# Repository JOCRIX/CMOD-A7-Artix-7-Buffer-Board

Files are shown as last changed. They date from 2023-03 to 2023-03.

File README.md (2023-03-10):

# **Buffer Board for the CMOD A7 Artix 7 family of FPGA development boards**


## **Purpose of the project**
The development boards for these FPGA's are costly and, sadly, a little fumbling around
could easily claim it's life, so, the purpose of this project is to create a board that can buffer the I/O pins
on the Digilent CMOD A7 FPGA board. (Mfr: 410-328-35, Mouser.com nr:424-410-328-35).

All design files are for KiCad. Feel free to export the GERBERS and do w/e with it.

## **How it works**
The board uses TXB0108 bidirectional and auto-direction sensing buffers to buffer all the I/O pins. The buffers
do not require any signal to set them as inputs or outputs, this is handled automatically on the fly. Each pin
has a maximum I/O current of 50mA and a package total of 100mA per buffer IC. The purpose of the board is 
that the drivers will fail before the FPGA does, that is OK. The FPGA is connected to the buffers through
330 ohm resistors, so, if the buffers fail in a spectacular way the FPGA output current is limited to stay
within specification of the Artix 7 35T FPGA.

The rise and fall times of the output of the buffer board has been tested and both rise and fall times are 4 < t < 5 [nS].

The two ADC input pins AIN/NP15, AIN/NP16 are protected against overvoltage conditions with diodes.

## **Requirements / BOM**

1x CMOD A7 FPGA Board - https://www.mouser.dk/ProductDetail/Digilent/410-328-35?qs=iHX4uCgIbgPRh1v3D3f51A%3D%3D
<br>
6x TXB0108 [TSSOP20]
<br>
11x YC324, or similar, 330 ohm resistor array.
<br>
2x 24 Pin Female headers with 2.54mm pitch
<br>
2x 24 Pin Female/Male header with 2.54mm pitch
<br>
1x LD117S533TR [SOT223]
<br>
7x 100nF >6.3V [0805]
<br>
1x 0603 LED (Doesn't really matter but it looks cool!)
<br>
1x 560R [0805]
<br>
1x 10uF [0805]
<br>
4x BAT54 [SOD-123]

## Hope you like Warhammer..



### Notes for users
V1 of this board has a fault so **PIO26 [FPGA PIN: R3] is not connected**. This is to be fixed in a future revision.
The problem can be fixed with a jumper wire for now. (Or just edit the .sch but w/e :)).

The green trace shows the connection that should be made for R3 to work. Easily fixed in either case..


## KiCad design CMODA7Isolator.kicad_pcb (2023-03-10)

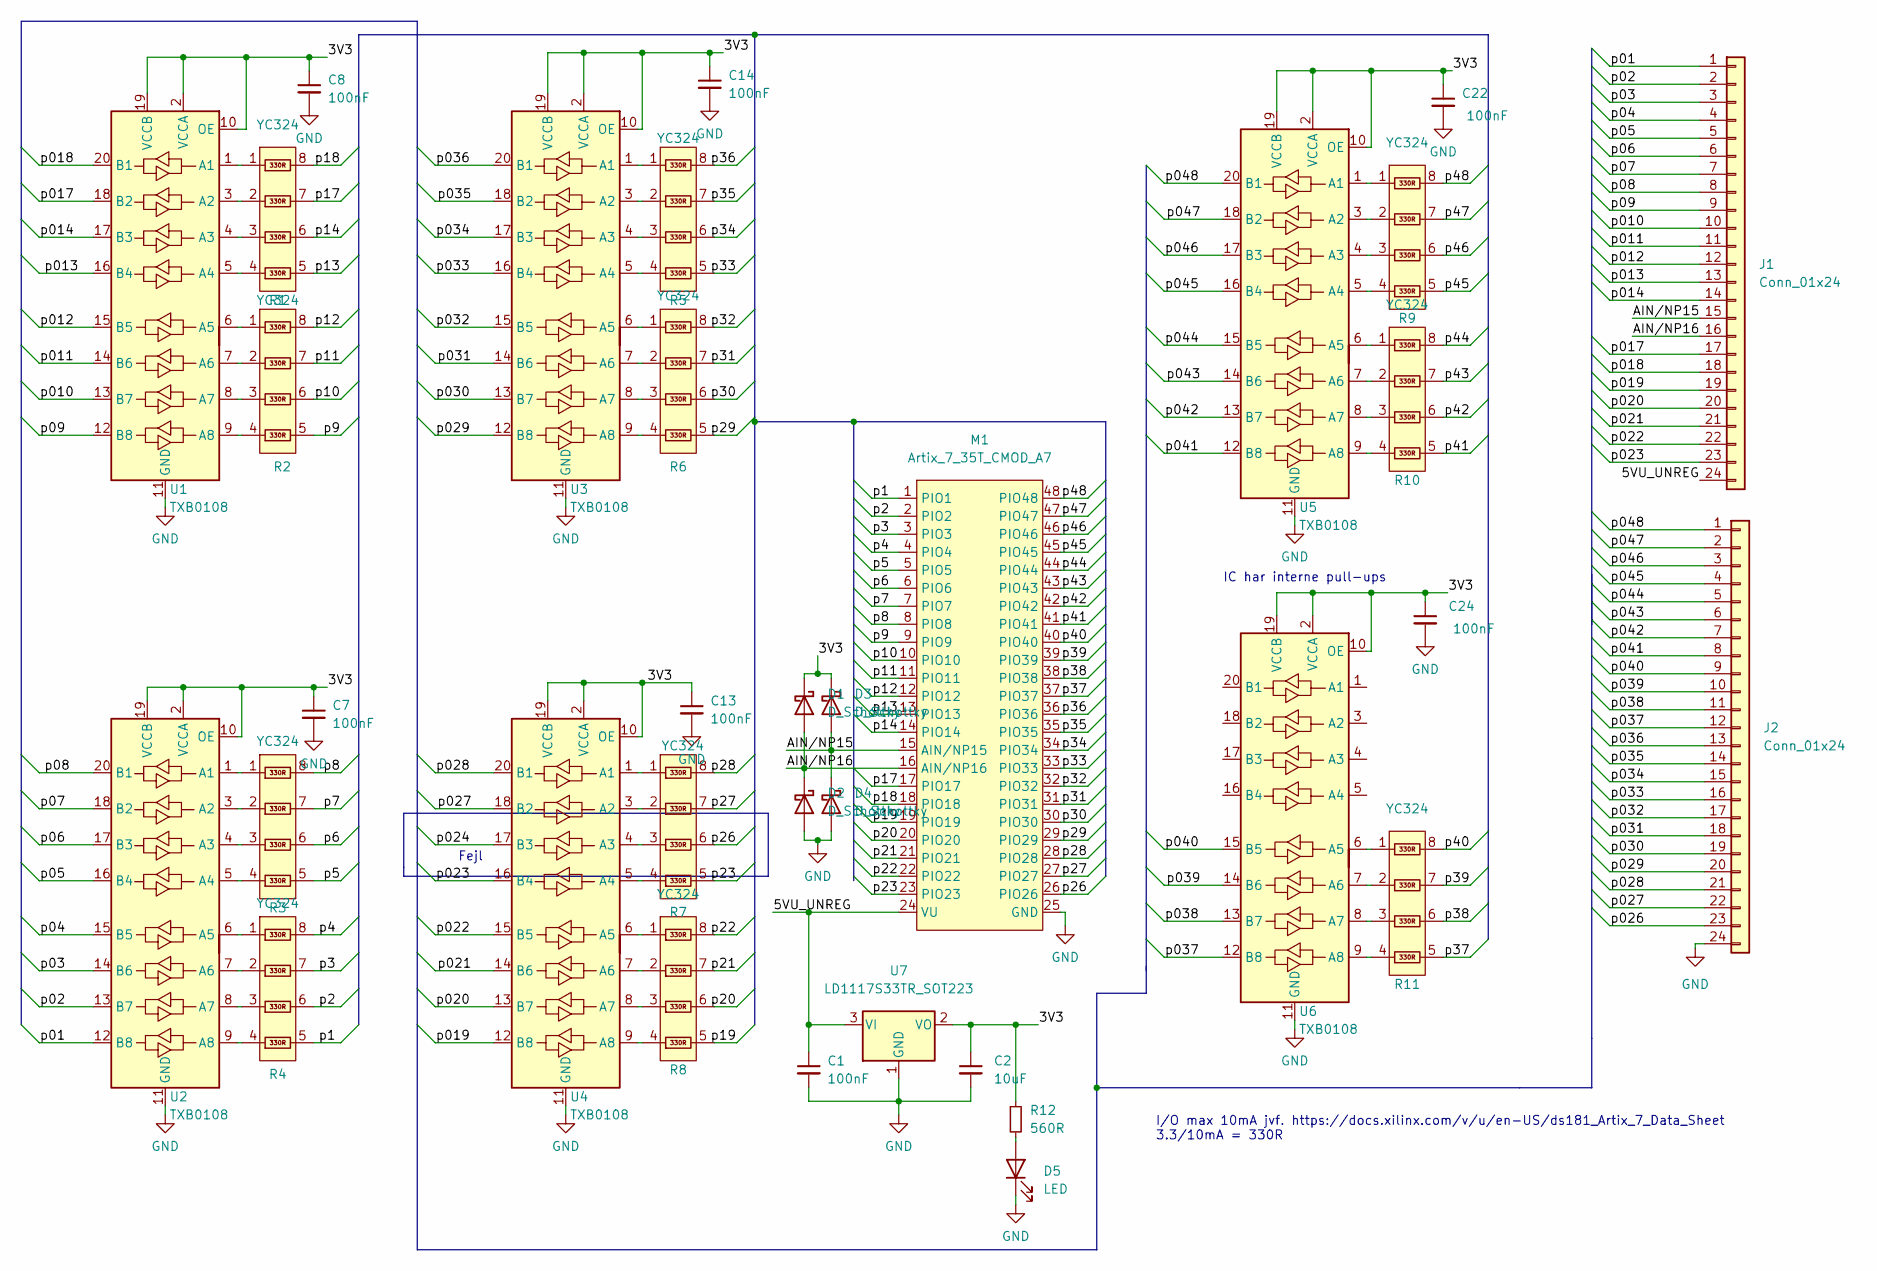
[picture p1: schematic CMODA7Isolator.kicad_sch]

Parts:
C1, C7, C8, C13, C14, C22, C24: 100nF; C_0805_2012Metric_Pad1.18x1.45mm_HandSolder
C2: 10uF; C_0805_2012Metric_Pad1.18x1.45mm_HandSolder
D1, D2, D3, D4: D_Schottky; D_SOD-123
D5: LED; LED_0603_1608Metric
J1, J2: Conn_01x24; PinHeader_1x24_P2.54mm_Vertical
M1: Artix_7_35T_CMOD_A7; CMOD A7 Module
R1, R2, R3, R4, R5, R6, R7, R8, R9, R10, R11: YC324; YC-TC 124 8Pin-4R
R12: 560R; R_0805_2012Metric_Pad1.20x1.40mm_HandSolder
U1, U2, U3, U4, U5, U6: TXB0108; TSSOP-20_4.4x6.5mm_P0.65mm
U7: LD1117S33TR_SOT223; SOT-223-3_TabPin2

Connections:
/3V3: C2.1, C7.1, C8.1, C13.1, C14.1, C22.1, C24.1, D1.1 (K), D3.1 (K), R12.1, U1.2 (VCCA), U1.10 (OE), U1.19 (VCCB), U2.2 (VCCA), U2.10 (OE), U2.19 (VCCB), U3.2 (VCCA), U3.10 (OE), U3.19 (VCCB), U4.2 (VCCA), U4.10 (OE), U4.19 (VCCB), U5.2 (VCCA), U5.10 (OE), U5.19 (VCCB), U6.2 (VCCA), U6.10 (OE), U6.19 (VCCB), U7.2 (VO)
/5VU_UNREG: C1.1, J1.24, M1.24 (VU), U7.3 (VI)
/AIN/NP15: D3.2 (A), D4.1 (K), J1.15, M1.15 (AIN/NP15)
/AIN/NP16: D1.2 (A), D2.1 (K), J1.16, M1.16 (AIN/NP16)
/p01: J1.1, U2.12 (B8)
/p1: M1.1 (PIO1), R4.5
/p02: J1.2, U2.13 (B7)
/p2: M1.2 (PIO2), R4.6
/p03: J1.3, U2.14 (B6)
/p3: M1.3 (PIO3), R4.7
/p04: J1.4, U2.15 (B5)
/p4: M1.4 (PIO4), R4.8
/p5: M1.5 (PIO5), R3.5
/p05: J1.5, U2.16 (B4)
/p6: M1.6 (PIO6), R3.6
/p06: J1.6, U2.17 (B3)
/p7: M1.7 (PIO7), R3.7
/p07: J1.7, U2.18 (B2)
/p8: M1.8 (PIO8), R3.8
/p08: J1.8, U2.20 (B1)
/p09: J1.9, U1.12 (B8)
/p9: M1.9 (PIO9), R2.5
/p010: J1.10, U1.13 (B7)
/p10: M1.10 (PIO10), R2.6
/p011: J1.11, U1.14 (B6)
/p11: M1.11 (PIO11), R2.7
/p012: J1.12, U1.15 (B5)
/p12: M1.12 (PIO12), R2.8
/p013: J1.13, U1.16 (B4)
/p13: M1.13 (PIO13), R1.5
/p014: J1.14, U1.17 (B3)
/p14: M1.14 (PIO14), R1.6
/p017: J1.17, U1.18 (B2)
/p17: M1.17 (PIO17), R1.7
/p018: J1.18, U1.20 (B1)
/p18: M1.18 (PIO18), R1.8
/p19: M1.19 (PIO19), R8.5
/p019: J1.19, U4.12 (B8)
/p20: M1.20 (PIO20), R8.6
/p020: J1.20, U4.13 (B7)
/p21: M1.21 (PIO21), R8.7
/p021: J1.21, U4.14 (B6)
/p22: M1.22 (PIO22), R8.8
/p022: J1.22, U4.15 (B5)
/p23: M1.23 (PIO23), R7.5
/p023: J1.23, U4.16 (B4)
/p024: U4.17 (B3)
/p26: M1.26 (PIO26), R7.6
/p026: J2.23
/p27: M1.27 (PIO27), R7.7
/p027: J2.22, U4.18 (B2)
/p28: M1.28 (PIO28), R7.8
/p028: J2.21, U4.20 (B1)
/p29: M1.29 (PIO29), R6.5
/p029: J2.20, U3.12 (B8)
/p30: M1.30 (PIO30), R6.6
/p030: J2.19, U3.13 (B7)
/p31: M1.31 (PIO31), R6.7
/p031: J2.18, U3.14 (B6)
/p32: M1.32 (PIO32), R6.8
/p032: J2.17, U3.15 (B5)
/p33: M1.33 (PIO33), R5.5
/p033: J2.16, U3.16 (B4)
/p34: M1.34 (PIO34), R5.6
/p034: J2.15, U3.17 (B3)
/p35: M1.35 (PIO35), R5.7
/p035: J2.14, U3.18 (B2)
/p36: M1.36 (PIO36), R5.8
/p036: J2.13, U3.20 (B1)
/p37: M1.37 (PIO37), R11.5
/p037: J2.12, U6.12 (B8)
/p38: M1.38 (PIO38), R11.6
/p038: J2.11, U6.13 (B7)
/p39: M1.39 (PIO39), R11.7
/p039: J2.10, U6.14 (B6)
/p40: M1.40 (PIO40), R11.8
/p040: J2.9, U6.15 (B5)
/p41: M1.41 (PIO41), R10.5
/p041: J2.8, U5.12 (B8)
/p42: M1.42 (PIO42), R10.6
/p042: J2.7, U5.13 (B7)
/p43: M1.43 (PIO43), R10.7
/p043: J2.6, U5.14 (B6)
/p44: M1.44 (PIO44), R10.8
/p044: J2.5, U5.15 (B5)
/p45: M1.45 (PIO45), R9.5
/p045: J2.4, U5.16 (B4)
/p46: M1.46 (PIO46), R9.6
/p046: J2.3, U5.17 (B3)
/p47: M1.47 (PIO47), R9.7
/p047: J2.2, U5.18 (B2)
/p48: M1.48 (PIO48), R9.8
/p048: J2.1, U5.20 (B1)
GND: C1.2, C2.2, C7.2, C8.2, C13.2, C14.2, C22.2, C24.2, D2.2 (A), D4.2 (A), D5.1 (K), J2.24, M1.25 (GND), U1.11 (GND), U2.11 (GND), U3.11 (GND), U4.11 (GND), U5.11 (GND), U6.11 (GND), U7.1 (GND)
unnamed: R1.1, U1.1 (A1)
unnamed: R1.2, U1.3 (A2)
unnamed: R1.3, U1.4 (A3)
unnamed: R1.4, U1.5 (A4)
unnamed: R2.1, U1.6 (A5)
unnamed: R2.2, U1.7 (A6)
unnamed: R2.3, U1.8 (A7)
unnamed: R2.4, U1.9 (A8)
unnamed: R3.1, U2.1 (A1)
unnamed: R3.2, U2.3 (A2)
unnamed: R3.3, U2.4 (A3)
unnamed: R3.4, U2.5 (A4)
unnamed: R4.1, U2.6 (A5)
unnamed: R4.2, U2.7 (A6)
unnamed: R4.3, U2.8 (A7)
unnamed: R4.4, U2.9 (A8)
unnamed: R5.1, U3.1 (A1)
unnamed: R5.2, U3.3 (A2)
unnamed: R5.3, U3.4 (A3)
unnamed: R5.4, U3.5 (A4)
unnamed: R6.1, U3.6 (A5)
unnamed: R6.2, U3.7 (A6)
unnamed: R6.3, U3.8 (A7)
unnamed: R6.4, U3.9 (A8)
unnamed: R7.1, U4.1 (A1)
unnamed: R7.2, U4.3 (A2)
unnamed: R7.3, U4.4 (A3)
unnamed: R7.4, U4.5 (A4)
unnamed: R8.1, U4.6 (A5)
unnamed: R8.2, U4.7 (A6)
unnamed: R8.3, U4.8 (A7)
unnamed: R8.4, U4.9 (A8)
unnamed: R9.1, U5.1 (A1)
unnamed: R9.2, U5.3 (A2)
unnamed: R9.3, U5.4 (A3)
unnamed: R9.4, U5.5 (A4)
unnamed: R10.1, U5.6 (A5)
unnamed: R10.2, U5.7 (A6)
unnamed: R10.3, U5.8 (A7)
unnamed: R10.4, U5.9 (A8)
unnamed: R11.1, U6.6 (A5)
unnamed: R11.2, U6.7 (A6)
unnamed: R11.3, U6.8 (A7)
unnamed: R11.4, U6.9 (A8)
unnamed: D5.2 (A), R12.2

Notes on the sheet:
I/O max 10mA jvf. https://docs.xilinx.com/v/u/en-US/ds181_Artix_7_Data_Sheet 3.3/10mA = 330R
IC har interne pull-ups
Fejl

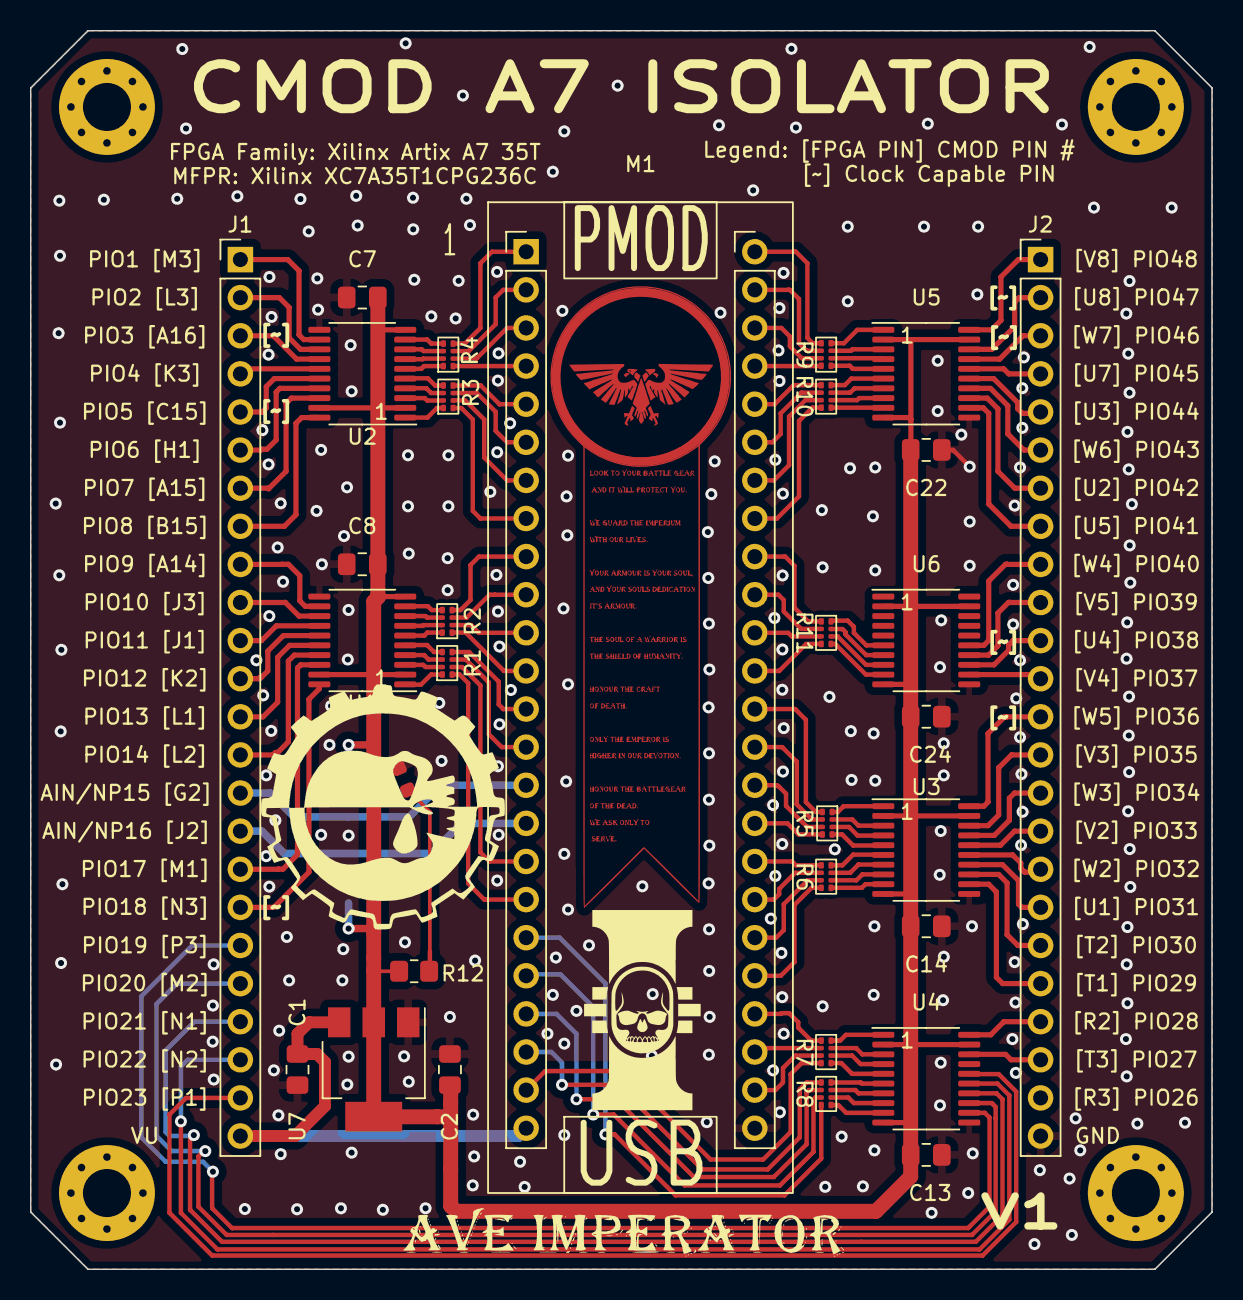
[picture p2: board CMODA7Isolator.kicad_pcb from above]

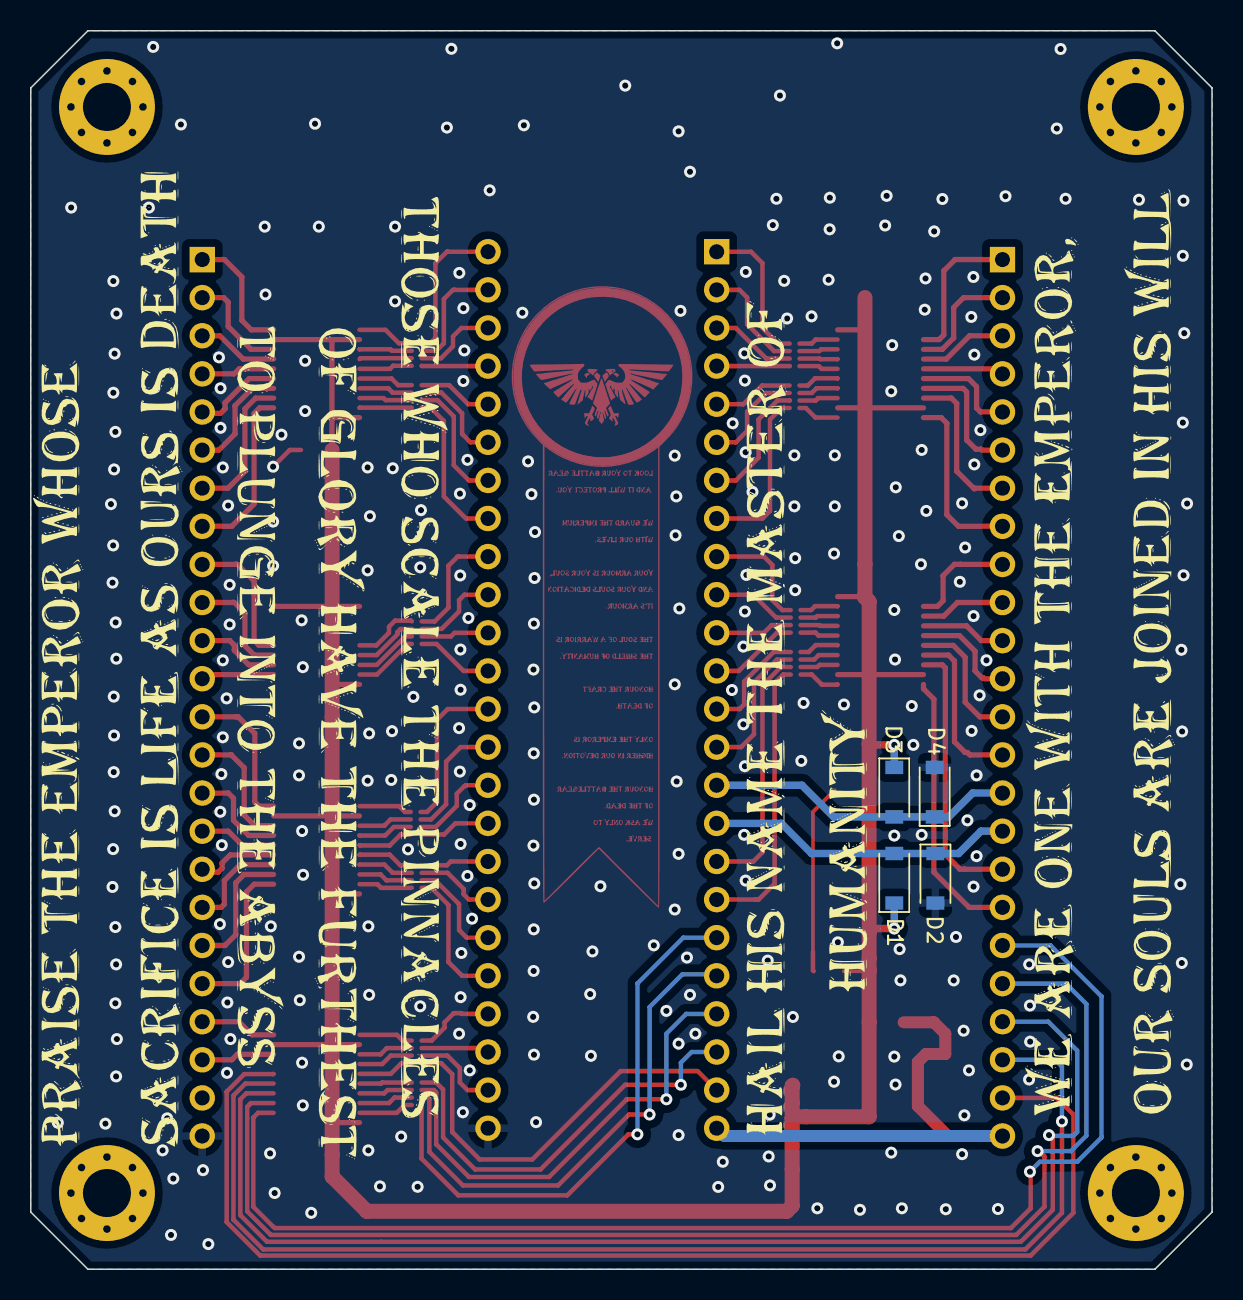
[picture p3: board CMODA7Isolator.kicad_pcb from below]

Board: 2 copper layers, 78.7 x 82.6 mm, 35 parts (4 on the bottom side), 137 nets.

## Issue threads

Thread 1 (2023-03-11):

Add Level Translating functionality

JOCRIX, 2023-03-11:
Sides A and B of the TXB0108's are currently both tied to 3.3V.

Make side B (output) switchable between 3.3V and 5V.

Make the switch happen with jumpers or DIP switches or something

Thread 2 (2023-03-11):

Change U4's position on the PCB

JOCRIX, 2023-03-11:
U4 should (possibly) be moved to the left of the CMOD, where the 3.3V regulator currently sits to shorten distance to pins.

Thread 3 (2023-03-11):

U4 schematic error and disconnected I/O pin

JOCRIX, 2023-03-11:
Fix the connection in the .sch on U4's A3 and B3 buffer. Input bus connection is marked p26 and output bus connection marked p024. Causes a disconnected from output of the buffer to pin header J2 pin 23.

JOCRIX, 2023-03-11:
Fixed

Closed 2023-03-11.

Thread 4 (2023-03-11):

More power pins

JOCRIX, 2023-03-11:
Add more power output pins to the board.

Add the regulated 3V3 to output pins and possibly 5V (refer to #1 )

Closed 2023-03-11.

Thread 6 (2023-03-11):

ADC input pin overvoltage

JOCRIX, 2023-03-11:
ADC input voltage range is (0-1V) (-0.5 - 0.5V) Update diode circuit together with issue #1

JOCRIX, 2023-03-11:
Fixed

Closed 2023-03-11.
